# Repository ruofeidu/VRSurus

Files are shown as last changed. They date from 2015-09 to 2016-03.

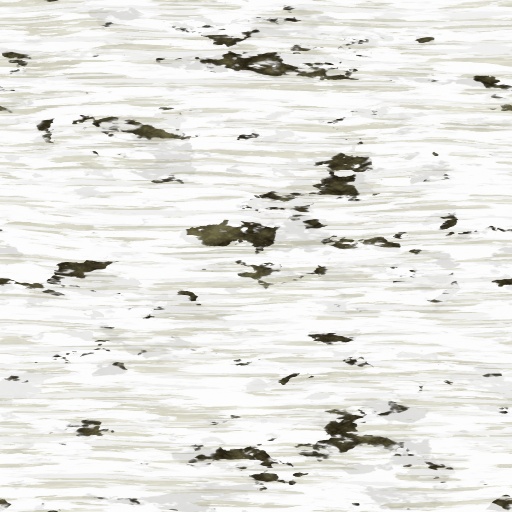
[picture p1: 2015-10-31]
images/bark3-diffuse.jpg

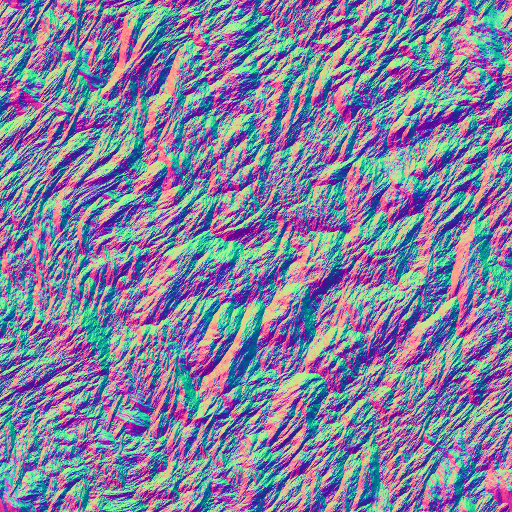
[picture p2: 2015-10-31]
images/bark-normal.jpg

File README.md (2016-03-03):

# VRSurus: A Tangible Virtual-Reality Game for Environmental Protection

### Introduction
We introduce VRSurus, a tangible serious game that aims to inspire children to protect the environment in immersive virtual reality (VR). VRSurus is built upon a physical puppet and a VR head-mounted display (Oculus Rift DK2) to create "tangible virtual animatronics". The player will act as a little elephant called Surus to prevent evil humanbeings from invading the forest. The player is able to use four gestures to cast magical spells: swiping left, swiping right, shaking and jumping. Servos, selonoids and vibration motors will assist with the puppet animation visible to the audience and provide haptic feedback for the player. VRSurus contributes to the HCI, animatronics and tangible computing community by integrating immersive interactive graphics together with gesture recognition and tangible feedback. The game is presented at the UIST 2015 Student Innovation Contest. Video and more details will be publicly available via www.vrsurus.com.

### Story Background
Once upon a time, there was a little elephant named Surus, living happily in a beautiful forest - Green Woodland.
However, in a cloudy day, evil human beings started to invade Green Woodland. They threw garbage everywhere; they used axes to cut down green trees; they even started to construct factories to pollute the air!
The magical elf of Green Woodland assigned you, Surus, to save the forest and rescue the nature! Surus is empowered with the magic of wind, water and fire to destroy the messy garbage, evil lumbermen and destructive factories. 

### Technical Brief
The software is built with WebGL and WebVR, which enables the game to be cross-platform for Oculus Rift and Google Cardboard. We rendered photo-realistic forest environment, GPU-based particle effects as well as skeleton-animated elephants, lumberman and factory. We use HTML5 (WebGL, WebVR, 3D Audio API), Javascript (jQuery & Three.js), GLSL ES (WebGL), PHP (ThinkPHP), MySQL and Java (Processing) to implement the entire system. 

The hardware consists of gyroscope, accelerometer, compass, servos, vibration motors, selonoids, batteries, 3D-printed skeletons and cases. 

### Authors
We the NinjaTerp team! Feel free to visit VRSurus.com for more information!
* Ruofei Du (http://duruofei.com)
   *  [Augmentarium Lab] | [UMIACS] | [University of Maryland, College Park]
   * Team Captain, Graphics (WebGL + WebVR + Model + 3D Audio) and Web Server (PHP + MySQL + Part of Java)
* Liang He (http://lianghe.me)
   * Makeability Lab | [HCIL] | [UMIACS] | [University of Maryland, College Park] 
   * Fabrication (3D Modeling, Printing), Logo, Video and Hardware (Arduino, Java)

### Advisor
* Amitabh Varshney (http://www.cs.umd.edu/~varshney)

### Presentation
The game is presented on UIST 2015 Student Innovation Contest. The project is still work-in-progress for future publications. For now, please cite
> Du, R., He, L. VRSurus: Enhancing Interactivity and Tangibility of Puppets in Virtual Reality. In Proceedings of the 33rd Annual ACM Conference Extended Abstracts on Human Factors in Computing Systems (CHI 16), 8 pages. ACM.

If you find our idea or code useful for your projects.

### How to Use
Feel free to run the entire codebase or build partial code such as only the VR game or only the open-sourced hardware.

##### VRSurus Game
The game is running a webserver with WebGL and WebVR technologies. Here is a step-by-step tutorial:
* Install [XAMPP] to setup a PHP + Apache + MySQL environment.
* Run Apache and MySQL server.
* Clone the git reporsitory and place all code into the XAMPP folder under htdocx/ninjaterp
* Open http://localhost/PHPMyAdmin, Create a new table called vrsurus and import the MySQL data from server/mysql/mysql.sql into the vrsurus table.
* Download the [Oculus Runtime] (v0.6.1 tested, v0.8 should also work) and [Chromium build for WebVR]
* Run http://localhost/ninjaterp using [Chromium build for WebVR]
* Press space on the keyboard to start the tutorial, press enter on the keyboard to start the game.
* You can control Surus using three ways:
    * Keyboard: 1, 2, 3, 4.
    * XBox: A, B, X, Y.
    * Puppet: Swipe left, swipe right, shake, thrust.

If you start the game and observe the scene flying high into the sky, then probably you are not using the correct browser: [Chromium build for WebVR]
### Instructions
##### Gecture
Please close the mouth of the puppet when performing any gesture to attack enemies. Then open the mouth.

##### Wind Spells
Swipe leftward or rightward to clean the garbage.

##### Water Spell
Shake the nose up and down to sweep the lumberman(an) away

##### Fire Spell
Punch forward to destroy the evil factories.

### Code
[Code on Github]

### Technical Challenges
This project is realy ambitious. We iterate numerous times, tried and failed in both software and hardware: anmiated models & 3D printing & miniaturization. 

### Acknowledgement
The authors would like to thank [Sai Yuan] from Department of Animal and Avian Science of [University of Maryland, College Park] for helping with splendid sewing and awesome vocal, background music and audio effects. We also thank 3DRT.com for providing a student discount for the awesome 3D models. And, thanks to [Augmentarium Lab] for funding this project.

### License
Creative Commons  Attribution-NonCommercial 4.0 International 

### Version
1.0.0

[Code on Github]: https://github.com/animatronics/ninjaterp
[Augmentarium Lab]:http://augmentarium.umiacs.umd.edu
[GVIL]:http://www.cs.umd.edu/gvil/
[HCIL]:http://www.cs.umd.edu/hcil/
[UMIACS]:http://umiacs.umd.edu
[University of Maryland, College Park]:http://www.umd.edu
[XAMPP]: https://www.apachefriends.org/index.html
[Oculus Runtime]: https://developer.oculus.com/downloads/pc/0.6.0.1-beta/Oculus_Runtime_for_Windows/
[Chromium build for WebVR]: https://drive.google.com/folderview?id=0BzudLt22BqGRbW9WTHMtOWMzNjQ
[Sai Yuan]: http://veritayuan.com/

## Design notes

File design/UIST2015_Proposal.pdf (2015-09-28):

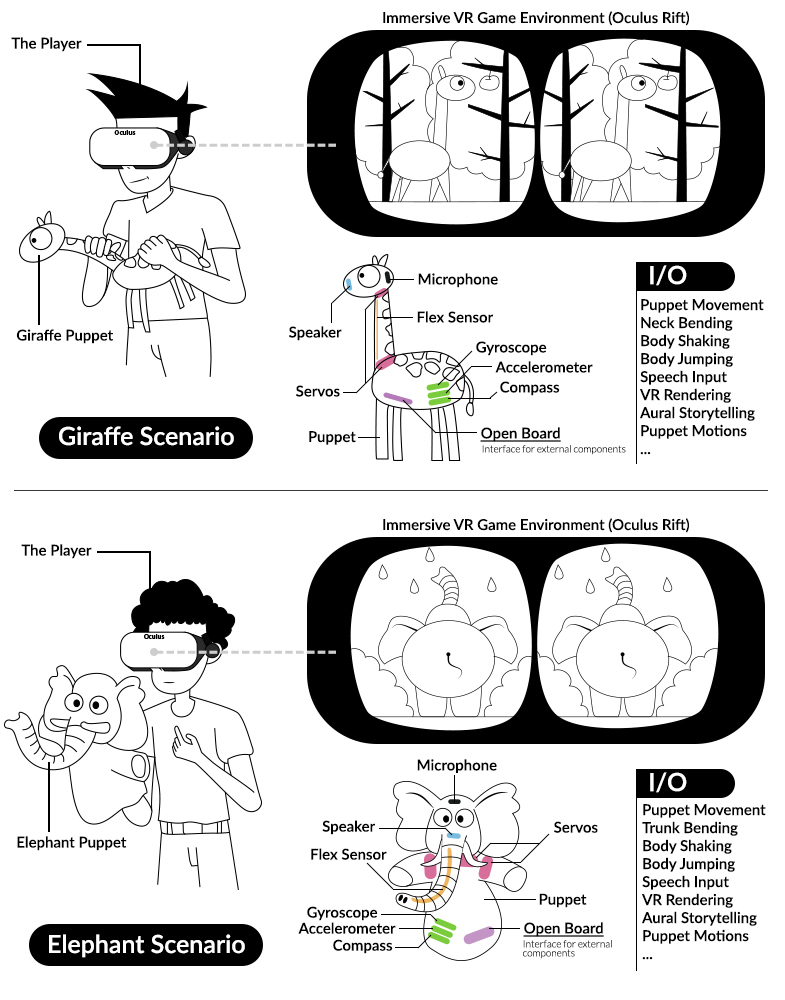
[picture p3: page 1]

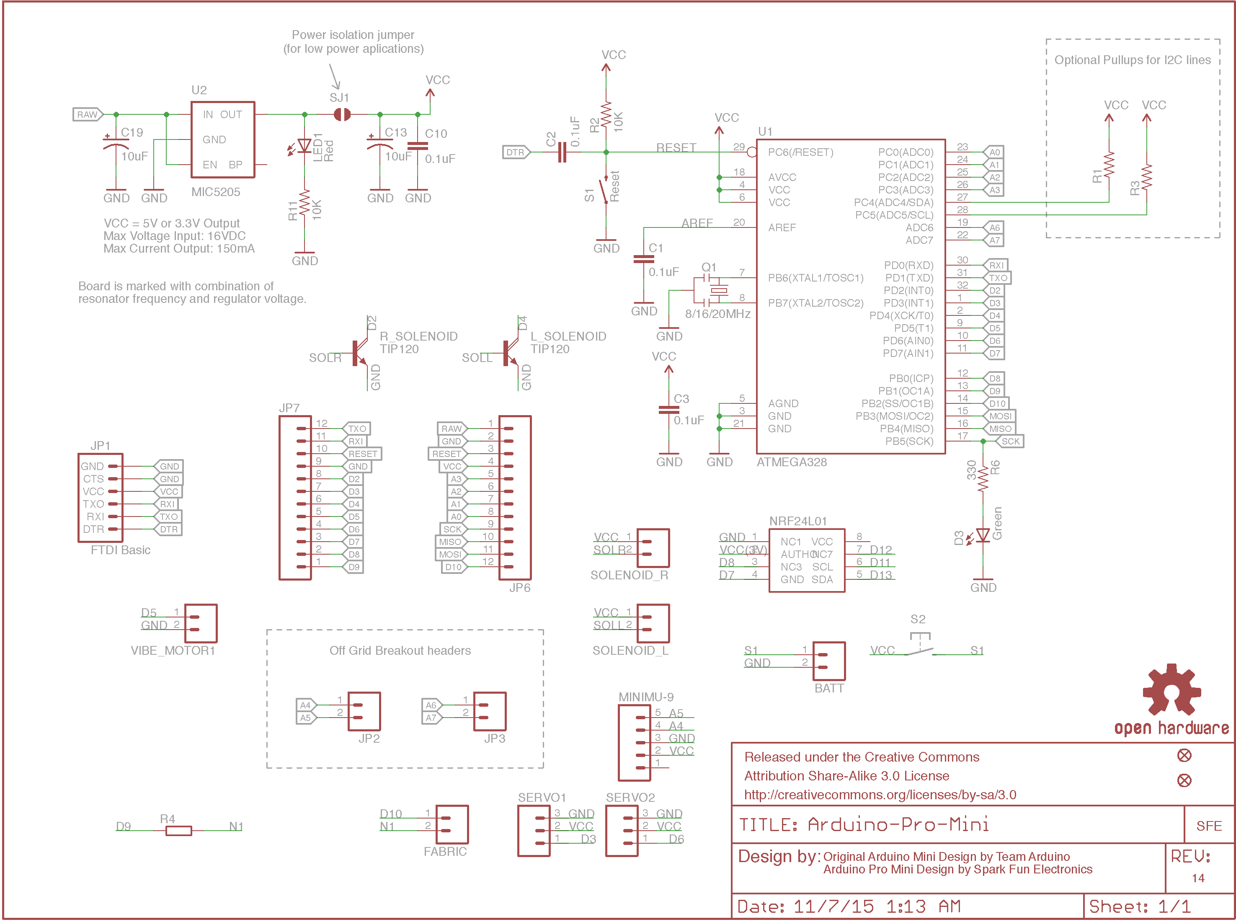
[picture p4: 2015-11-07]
hardware/circuit/Circuit.png

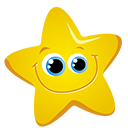
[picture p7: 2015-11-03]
images/star.png

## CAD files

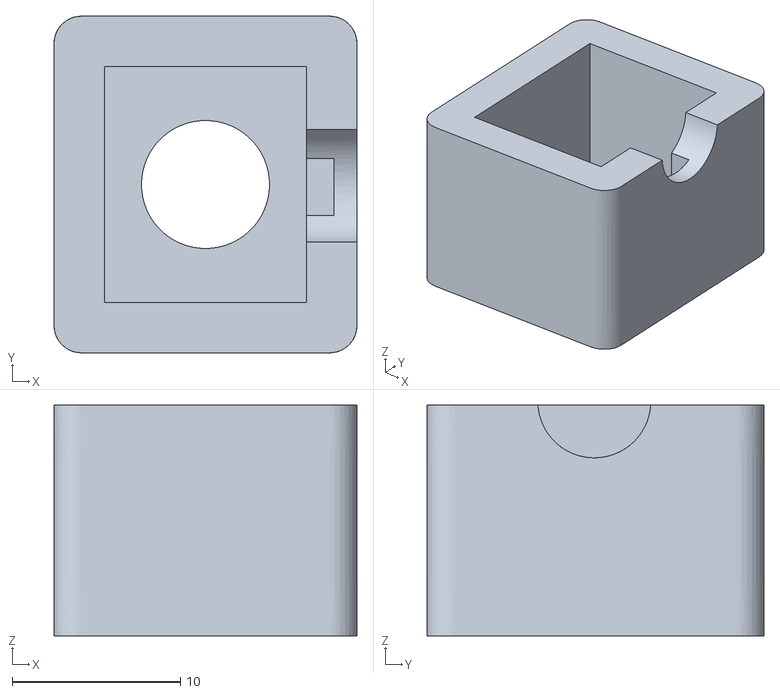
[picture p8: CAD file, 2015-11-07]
hardware/fabrication/solenoid_low1.stl
18.0 x 20.0 x 13.7

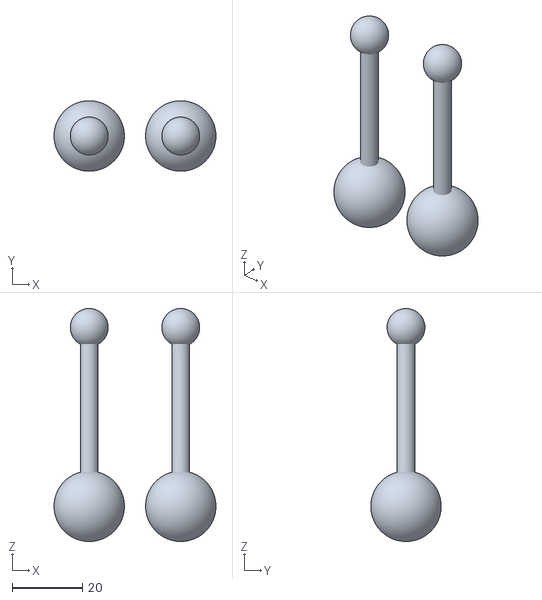
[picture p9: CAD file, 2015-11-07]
hardware/fabrication/arm.stl
46.0 x 20.0 x 66.2

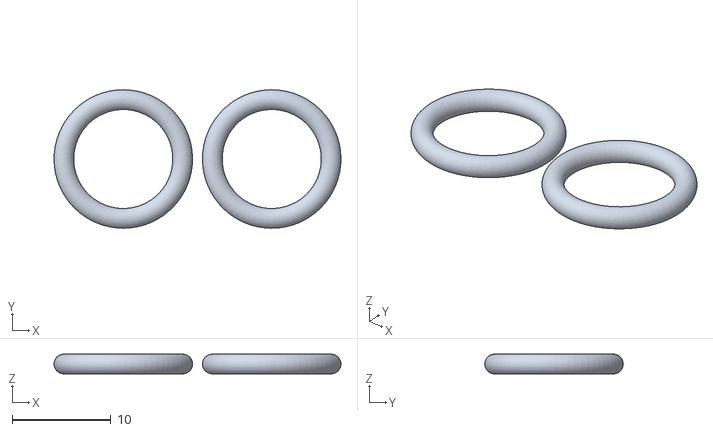
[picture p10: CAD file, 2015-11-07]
hardware/fabrication/arm_clip.stl
29.0 x 14.0 x 2.00

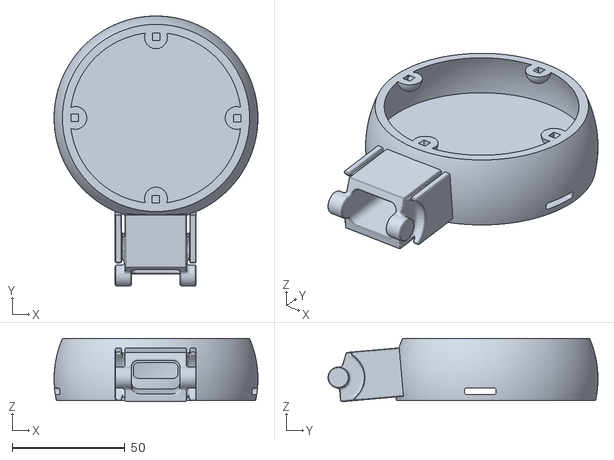
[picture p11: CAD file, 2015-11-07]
hardware/fabrication/cap_low_new.stl
90.6 x 120.0 x 28.1

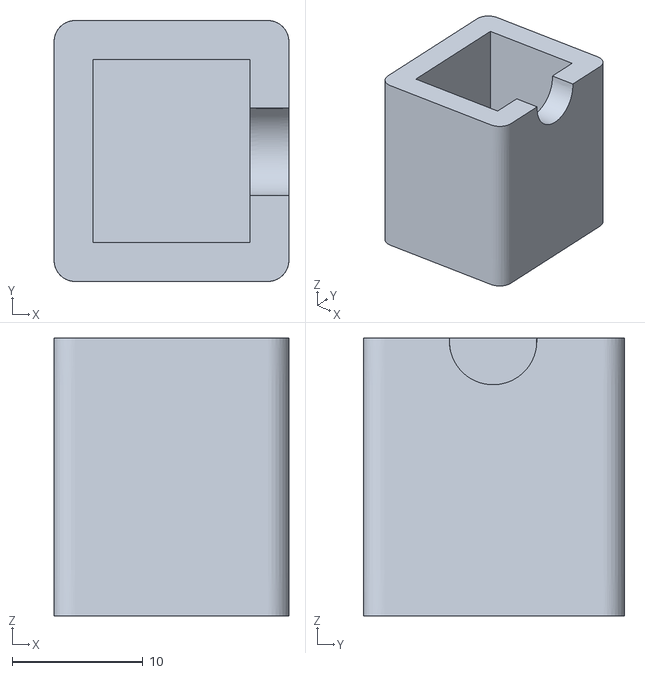
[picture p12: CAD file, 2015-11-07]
hardware/fabrication/solenoid_up1.stl
18.0 x 20.0 x 21.3

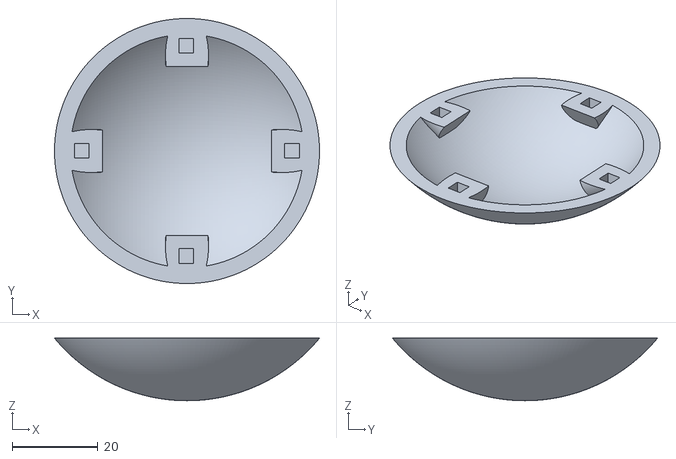
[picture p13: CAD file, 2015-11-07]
hardware/fabrication/cap_up.stl
61.7 x 61.7 x 14.6

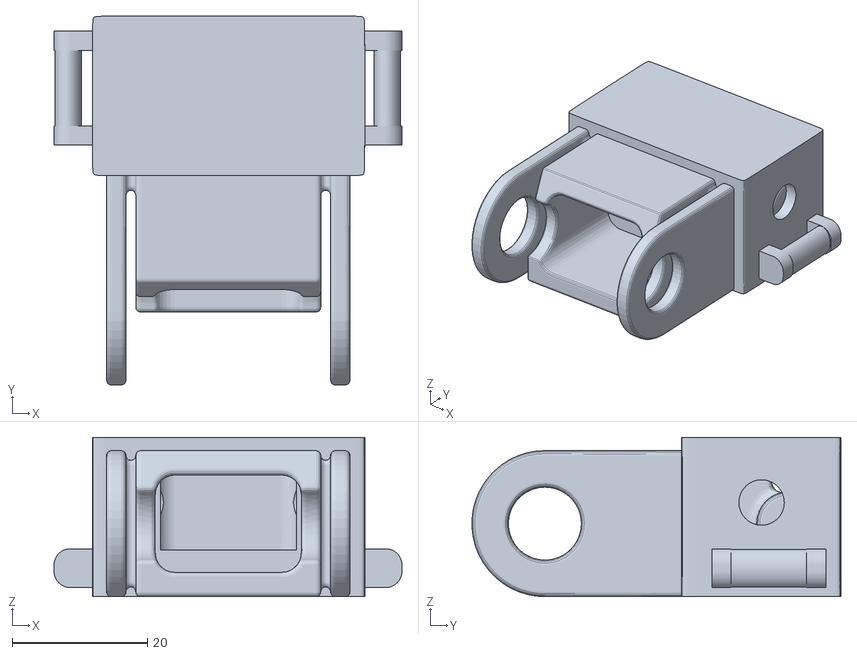
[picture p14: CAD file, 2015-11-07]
hardware/fabrication/end_node.stl
51.4 x 54.6 x 23.6

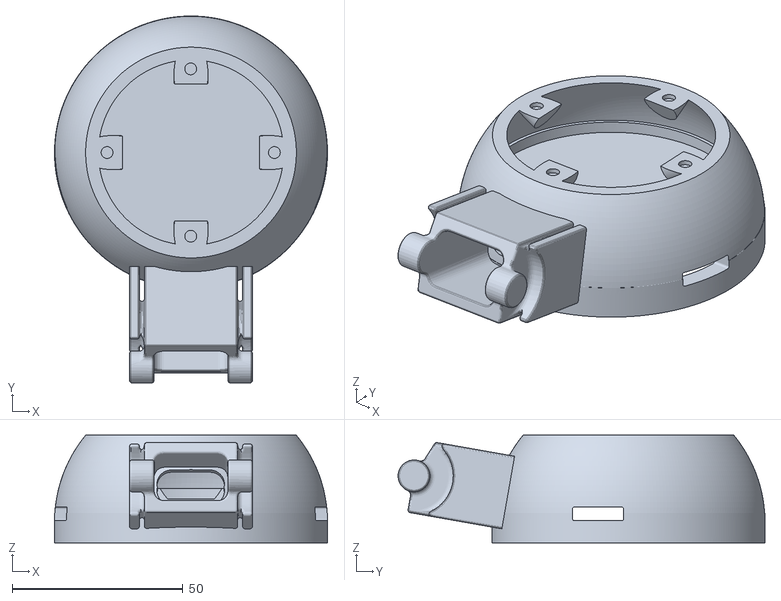
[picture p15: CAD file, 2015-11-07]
hardware/fabrication/cap_low.stl
80.0 x 107.5 x 31.6

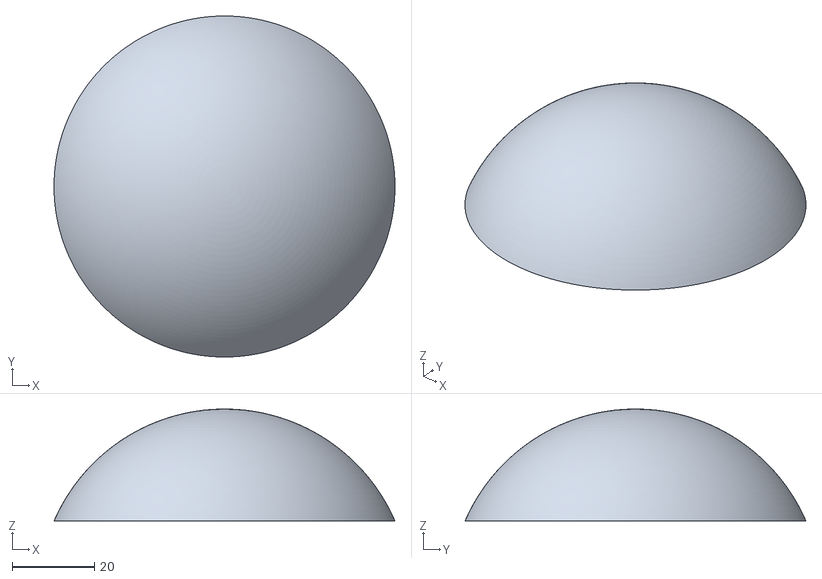
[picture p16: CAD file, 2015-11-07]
hardware/fabrication/cap_up_new.stl
83.1 x 83.1 x 27.3

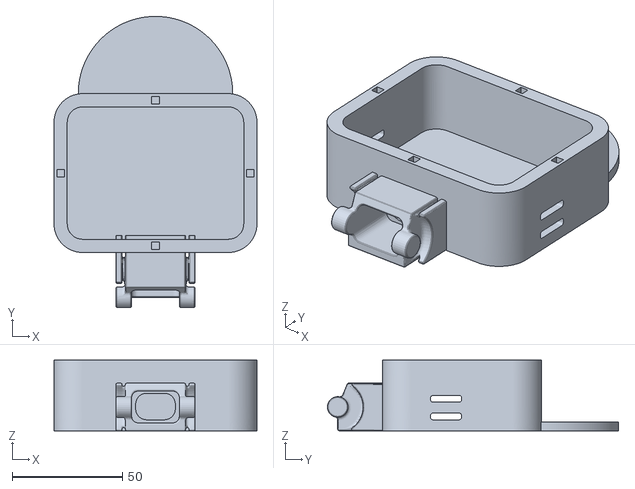
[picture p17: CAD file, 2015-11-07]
hardware/fabrication/cap_low_updated.stl
92.0 x 132.0 x 32.0

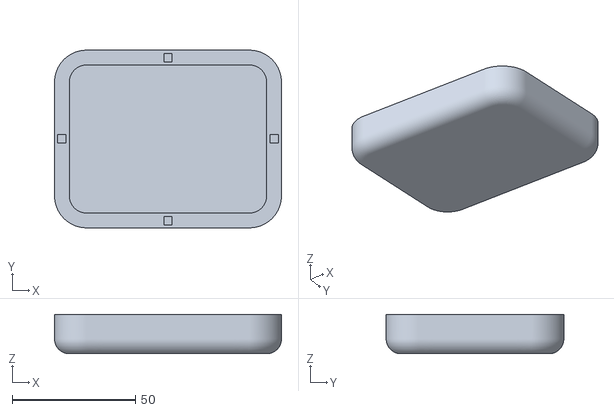
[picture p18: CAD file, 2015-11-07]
hardware/fabrication/cap_up_updated.stl
92.0 x 72.0 x 16.0

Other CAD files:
hardware/fabrication/solenoid_low2.stl
hardware/fabrication/solenoid_up2.stl
hardware/fabrication/accessaries.3dm
hardware/fabrication/end_node+solenoid_case.3dm

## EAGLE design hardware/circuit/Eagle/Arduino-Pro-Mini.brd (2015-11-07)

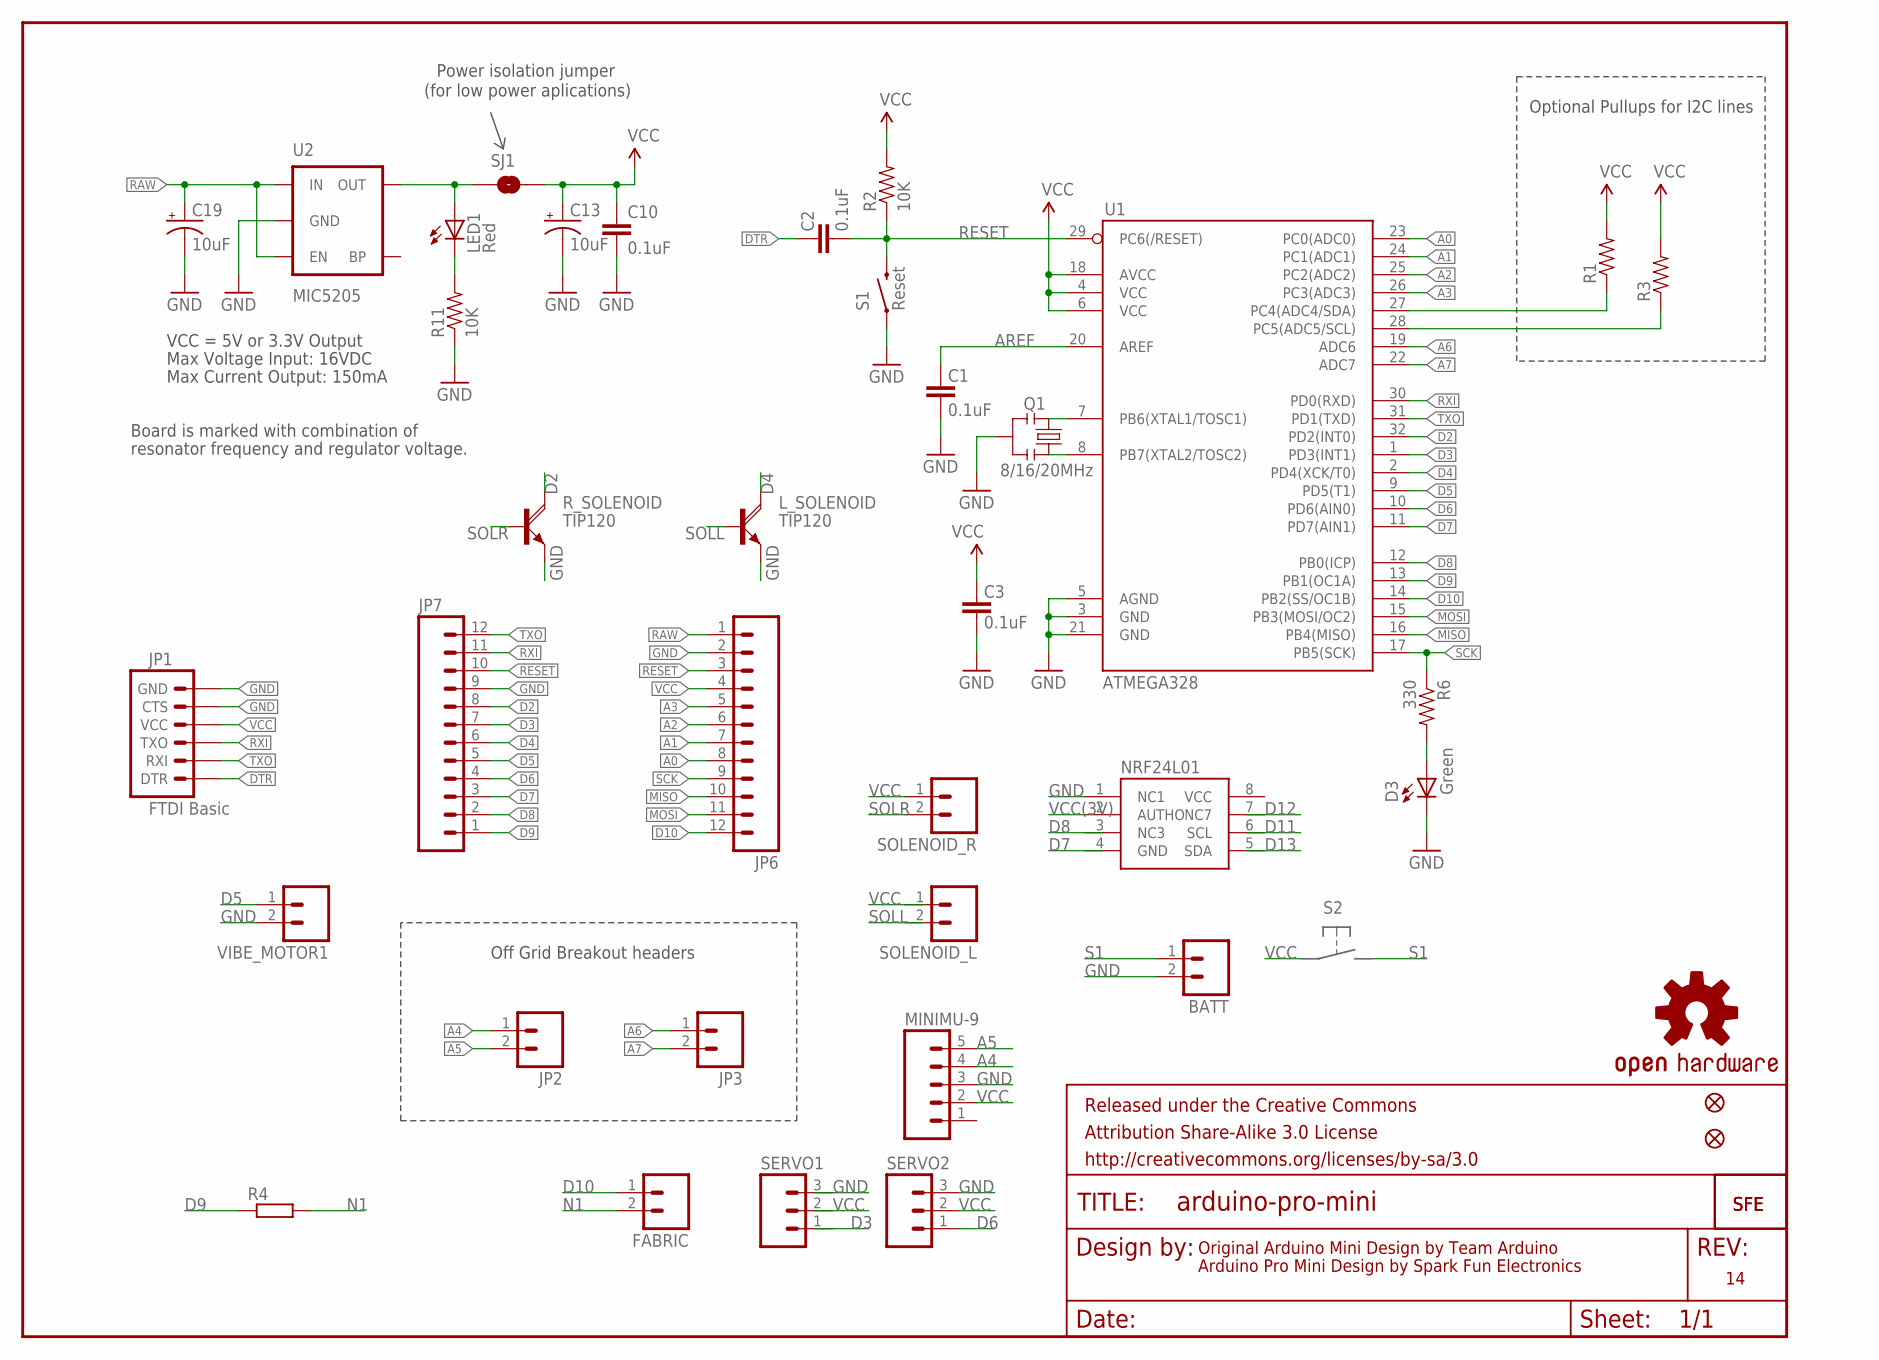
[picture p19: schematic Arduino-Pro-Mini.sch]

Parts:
BATT: M02PTH; 1X02
C1, C2, C3, C10: 0.1uF; 0603-CAP
C13, C19: 10uF; EIA3216
D3: Green; 0603-LED-ALT1
FABRIC: M02PTH; 1X02
FRAME1: FRAME-LETTER; CREATIVE_COMMONS
JP1: FTDI Basic; 1X06
JP2, JP3: M02PTH; 1X02
JP5, JP8: FIDUCIALUFIDUCIAL; MICRO-FIDUCIAL
JP6, JP7: M12PTH; 1X12
LED1: Red; 0603-LED-ALT1
L_SOLENOID: TIP120; TO220AH
MINIMU-9: M05; 05P
NRF24L01: ATAES132; SOIC8
Q1: 8/16/20MHz; RESONATOR-SMD-1:1
R1, R3: RESISTOR0603-RES; 0603-RES
R2, R11: 10K; 0603-RES
R4: R-EU_0204/5; 0204/5
R6: 330; 0603-RES
R_SOLENOID: TIP120; TO220AH
S1: Reset; TACTILE-SWITCH-SMD-ALT01
SERVO1, SERVO2: M03; 03P
SJ1: SOLDERJUMPERNC; SJ_2S
SOLENOID_L: M02PTH; 1X02
SOLENOID_R: M02PTH; 1X02
U1: ATMEGA328; TQFP32-08
U2: MIC5205; SOT23-5
U$1: LOGO-SFESK; SFE-LOGO-FLAME
U$3: OSHW-LOGOS; OSHW-LOGO-S
U$11: LOGO-SFENEW; SFE-NEW-WEBLOGO
VIBE_MOTOR1: M02PTH; 1X02

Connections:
A0: JP6.8, U1.23 (PC0(ADC0))
A1: JP6.7, U1.24 (PC1(ADC1))
A2: JP6.6, U1.25 (PC2(ADC2))
A3: JP6.5, U1.26 (PC3(ADC3))
A4: JP2.1, MINIMU-9.4, R1.1, U1.27 (PC4(ADC4/SDA))
A5: JP2.2, MINIMU-9.5, R3.1, U1.28 (PC5(ADC5/SCL))
A6: JP3.1, U1.19 (ADC6)
A7: JP3.2, U1.22 (ADC7)
AREF: C1.2, U1.20 (AREF)
D2: JP7.8, R_SOLENOID.C, U1.32 (PD2(INT0))
D3: JP7.7, U1.1 (PD3(INT1))
D4: JP7.6, L_SOLENOID.C, U1.2 (PD4(XCK/T0))
D5: JP7.5, U1.9 (PD5(T1)), VIBE_MOTOR1.1
D6: JP7.4, SERVO2.1, U1.10 (PD6(AIN0))
D7: JP7.3, U1.11 (PD7(AIN1))
D8: JP7.2, U1.12 (PB0(ICP))
D9: JP7.1, R4.1, U1.13 (PB1(OC1A))
D10: FABRIC.1, JP6.12, U1.14 (PB2(SS/OC1B))
DTR: C2.2, JP1.1 (DTR)
GND: BATT.2, C1.1, C3.1, C10.2, C13.C (-), C19.C (-), D3.C, JP1.5 (CTS), JP1.6 (GND), JP6.2, JP7.9, L_SOLENOID.E, MINIMU-9.3, NRF24L01.1 (NC1), NRF24L01.4 (GND), Q1.2, R11.1, R_SOLENOID.E, S1.1, S1.2 (1), SERVO2.3, U1.3 (GND), U1.5 (AGND), U1.21 (GND), U2.2 (GND), VIBE_MOTOR1.2
MISO: JP6.10, U1.16 (PB4(MISO))
MOSI: JP6.11, U1.15 (PB3(MOSI/OC2))
N1: FABRIC.2, R4.2
unnamed: Q1.3, U1.8 (PB7(XTAL2/TOSC2))
unnamed: Q1.1, U1.7 (PB6(XTAL1/TOSC1))
unnamed: LED1.A, SJ1.1, U2.5 (OUT)
unnamed: LED1.C, R11.2
unnamed: D3.A, R6.2
RAW: C19.A (+), JP6.1, U2.1 (IN), U2.3 (EN)
RESET: C2.1, JP6.3, JP7.10, R2.1, S1.3 (2), S1.4 (2), U1.29 (PC6(/RESET))
RXI: JP1.3 (TXO), JP7.11, U1.30 (PD0(RXD))
S1: BATT.1
SCK: JP6.9, R6.1, U1.17 (PB5(SCK))
SOLL: L_SOLENOID.B
SOLR: R_SOLENOID.B, SOLENOID_R.2
TXO: JP1.2 (RXI), JP7.12, U1.31 (PD1(TXD))
VCC: C3.2, C10.1, C13.A (+), JP1.4 (VCC), JP6.4, MINIMU-9.2, NRF24L01.8 (VCC), R1.2, R2.2, R3.2, SERVO2.2, SJ1.2, SOLENOID_R.1, U1.4 (VCC), U1.6 (VCC), U1.18 (AVCC)
VCC(3V): NRF24L01.2 (AUTHO)

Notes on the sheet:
Original Arduino Mini Design by Team Arduino
Arduino Pro Mini Design by Spark Fun Electronics
Max Voltage Input: 16VDC
Max Current Output: 150mA
Board is marked with combination of
resonator frequency and regulator voltage.
VCC = 5V or 3.3V Output
Optional Pullups for I2C lines
Off Grid Breakout headers
Power isolation jumper
(for low power aplications)

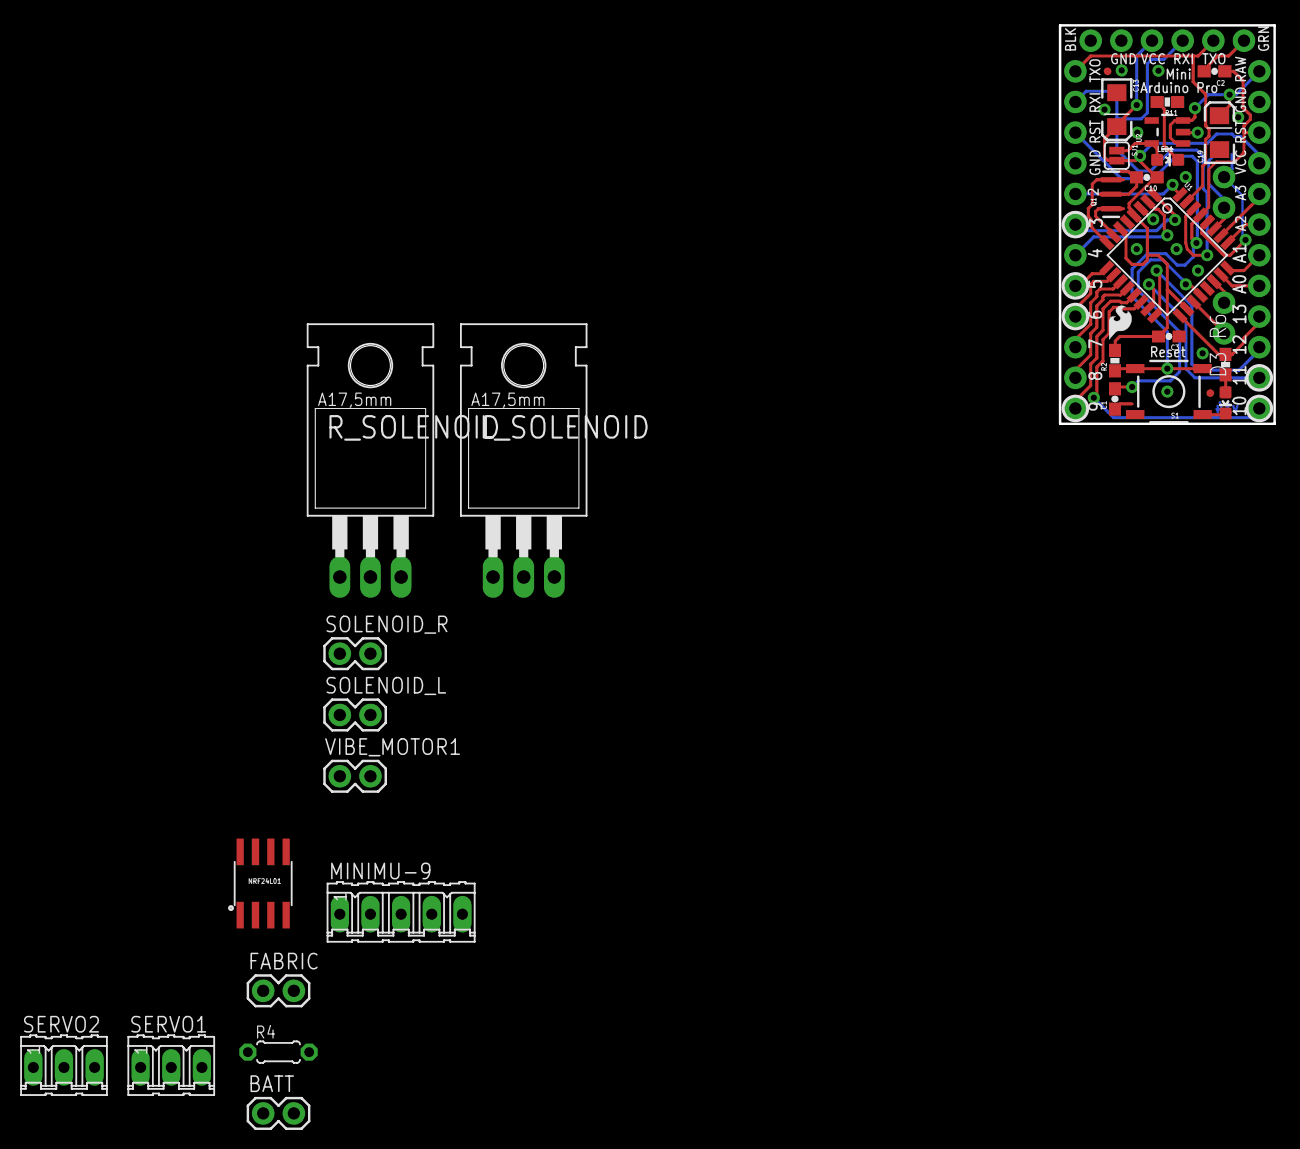
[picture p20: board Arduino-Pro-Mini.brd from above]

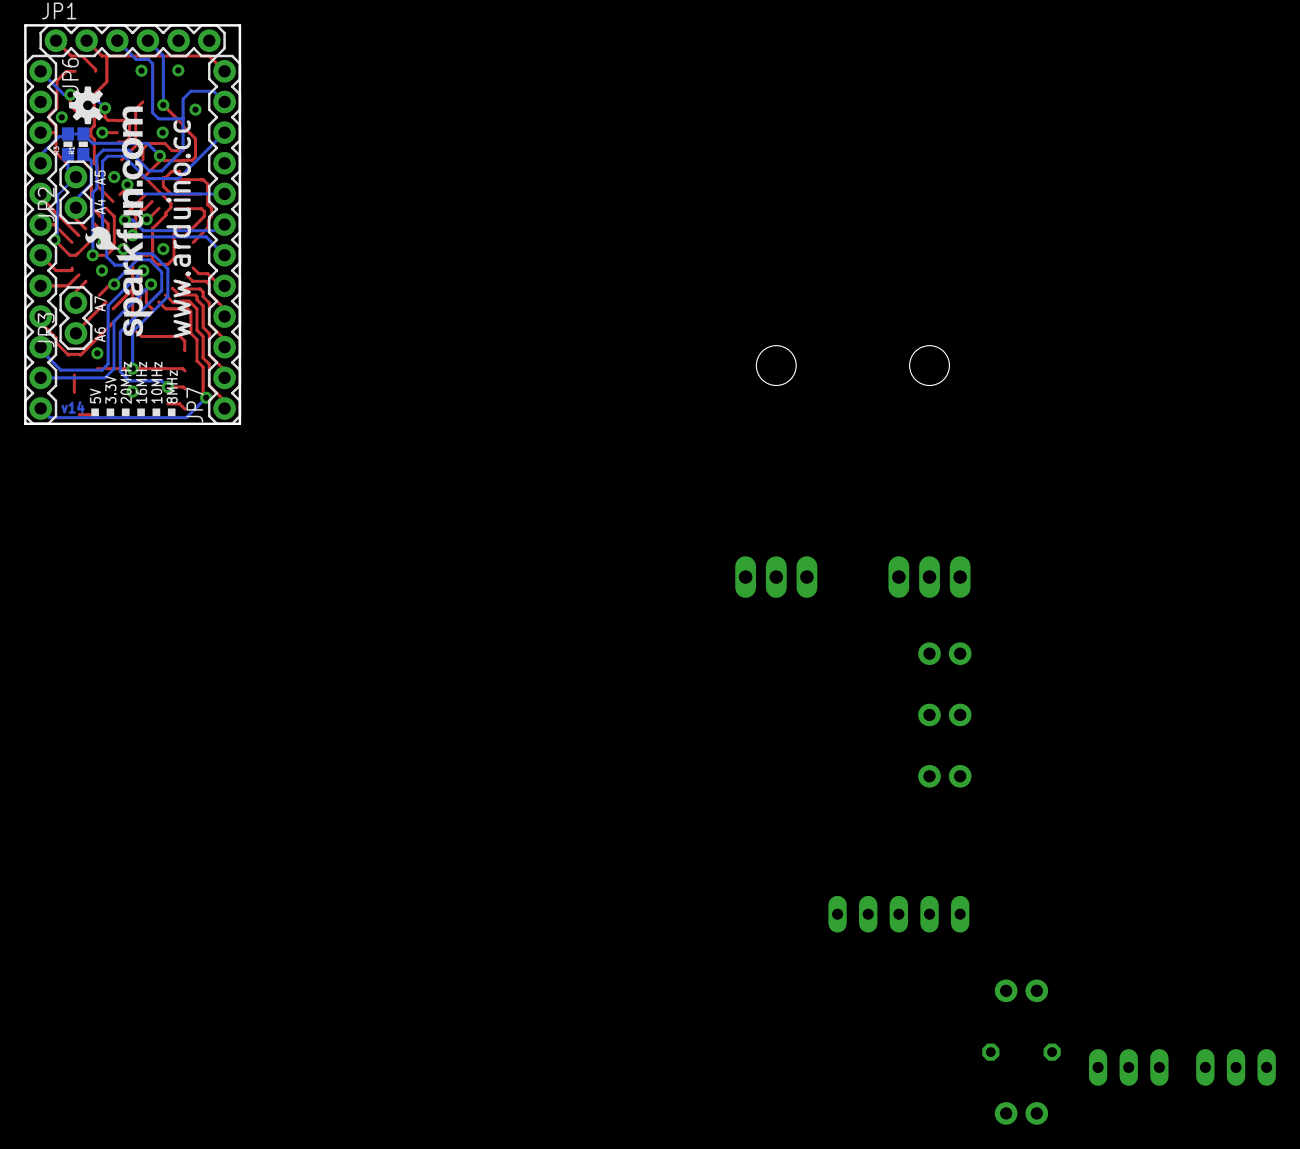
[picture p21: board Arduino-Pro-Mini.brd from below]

Board: 2 copper layers, 17.8 x 33.0 mm, 41 parts (9 on the bottom side), 35 nets.

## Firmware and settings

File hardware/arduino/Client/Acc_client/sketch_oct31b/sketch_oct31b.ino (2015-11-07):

#include <SPI.h>
#include <Mirf.h>
#include <MirfHardwareSpiDriver.h>
#include <MirfSpiDriver.h>
#include <nRF24L01.h>

#include <QueueList.h>

#include <Wire.h>
#include <LSM303.h>


LSM303 compass;

#define GRAVITY 256         // this equivalent to 1G in the raw data coming from the accelerometer 

// X axis pointing forward
// Y axis pointing to the right 
// and Z axis pointing down.
int SENSOR_SIGN[3] = {-1, -1, -1};  // correct directions x, y, z - accelerometer
int AN[3]; //array that stores accelerometer data
int AN_OFFSET[3] = {0,0,0}; //Array that stores the Offset of the sensors

int accel_x;
int accel_y;
int accel_z;

long timer=0;   //general purpuse timer
long timer_old;

void Accel_Init()
{
  compass.init();
  compass.enableDefault();
  switch (compass.getDeviceType())
  {
    case LSM303::device_D:
      compass.writeReg(LSM303::CTRL2, 0x18); // 8 g full scale: AFS = 011
      break;
    case LSM303::device_DLHC:
      compass.writeReg(LSM303::CTRL_REG4_A, 0x28); // 8 g full scale: FS = 10; high resolution output mode
      break;
    default: // DLM, DLH
      compass.writeReg(LSM303::CTRL_REG4_A, 0x30); // 8 g full scale: FS = 11
  }
}

// Reads x,y and z accelerometer registers
void Read_Accel()
{
  compass.readAcc();
  
  AN[0] = compass.a.x >> 4; // shift left 4 bits to use 12-bit representation (1 g = 256)
  AN[1] = compass.a.y >> 4;
  AN[2] = compass.a.z >> 4;
  accel_x = SENSOR_SIGN[0] * (AN[0] - AN_OFFSET[0]);
  accel_y = SENSOR_SIGN[1] * (AN[1] - AN_OFFSET[1]);
  accel_z = SENSOR_SIGN[2] * (AN[2] - AN_OFFSET[2]);
}

void I2C_Init()
{
  Wire.begin();
}

void setup() {
  Serial.begin(9600);
  
  I2C_Init();
  delay(1500);
  
  Accel_Init();
  delay(20);

  for (int i = 0; i < 32; i++)    // We take some readings...
  {
    Read_Accel();
    for (int y = 0; y < 3; y++)   // Cumulate values
      AN_OFFSET[y] += AN[y];
    delay(20);
  }

  for (int y = 0; y < 3; y++)
    AN_OFFSET[y] = AN_OFFSET[y]/32;

  AN_OFFSET[2] -= GRAVITY*SENSOR_SIGN[2];

  //Serial.println("Offset:");
  //for(int y=0; y<3; y++)
  //  Serial.println(AN_OFFSET[y]);

  delay(2000);
  timer = millis();
  delay(20);

  // Initialize the client
  Mirf.spi = &MirfHardwareSpi;
  Mirf.init();
  
  // Configure reciving address.
  Mirf.setRADDR((byte *)"clie1");
  Mirf.payload = 9;
  Mirf.config();
  Serial.println("Beginning ... "); 
}

void loop() {
  if ((millis()-timer) >= 1){  // Main loop runs at 1000Hz
    timer_old = timer;
    timer = millis();

    Read_Accel();

    byte data[Mirf.payload];
    byte temp;
    
    if (accel_x <= 0) {
      accel_x = -accel_x;
      data[0] = '-';
    } else {
      data[0] = '+';
    }
    data[1] = (byte)((accel_x & 0xFF00) >> 8);
    data[2] = (byte)(accel_x & 0xFF);

    if (accel_y <= 0) {
      accel_y = -accel_y;
      data[3] = '-';
    } else {
      data[3] = '+';
    }
    data[4] = (byte)((accel_y & 0xFF00) >> 8);
    data[5] = (byte)(accel_y & 0xFF);

    if (accel_z <= 0) {
      accel_z = -accel_z;
      data[6] = '-';
    } else {
      data[6] = '+';
    }
    data[7] = (byte)((accel_z & 0xFF00) >> 8);
    data[8] = (byte)(accel_z & 0xFF);

    // sending data
    Mirf.setTADDR((byte *)"serv1");
    Mirf.send(data);
    while(Mirf.isSending()){}
    Serial.println("Finished sending");
    
    Serial.println("Acc: ");
    Serial.print(data[0]);
    Serial.print(", ");
    Serial.print(data[1]);
    Serial.print(", ");
    Serial.println(data[2]);
  
    Serial.print(data[3]);
    Serial.print(", ");
    Serial.print(data[4]);
    Serial.print(", ");
    Serial.println(data[5]);
  
    Serial.print(data[6]);
    Serial.print(", ");
    Serial.print(data[7]);
    Serial.print(", ");
    Serial.println(data[8]);
    Serial.println("");
  }
}

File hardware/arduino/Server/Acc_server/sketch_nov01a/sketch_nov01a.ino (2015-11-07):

#include <SPI.h>
#include <Mirf.h>
#include <nRF24L01.h>
#include <MirfHardwareSpiDriver.h>

int accel_x, accel_y, accel_z;

void setup(){
  Serial.begin(9600);
  Mirf.spi = &MirfHardwareSpi;
  Mirf.init();

  Mirf.setRADDR((byte *)"serv1");

  Mirf.payload = 9;
  
  Mirf.config();

}

void loop(){

  byte data[Mirf.payload];
  

  if(!Mirf.isSending() && Mirf.dataReady()){
    
    Mirf.getData(data);
   
    // Mirf.setTADDR((byte *)"clie1");
    // Mirf.send(data);
    
    accel_x = data[1];
    accel_x = accel_x << 8 | data[2];
    if(data[0] == '-'){
      accel_x = -accel_x;
    }

    accel_y = data[4];
    accel_y = accel_y << 8 | data[5];
    if(data[3] == '-'){
      accel_y = -accel_y;
    }

    accel_z = data[7];
    accel_z = accel_z << 8 | data[8];
    if(data[6] == '-'){
      accel_z = -accel_z;
    }
    printData();
    
  }
  //printdata();
}

void printdata(void){
  Serial.print("Acc: ");
  Serial.print(accel_x);
  Serial.print(", ");
  Serial.print(accel_y);
  Serial.print(", ");
  Serial.println(accel_z);
}
void printData(void){
  Serial.print(accel_x);
  Serial.print(',');
  Serial.print(accel_y);
  Serial.print(',');
  Serial.print(accel_z);
  Serial.print('#');
}

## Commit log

2015-09-28 Added design and hardware
    [head-extender-20mm.stl, head-extender-40mm.stl, head-frame-short-mouth.stl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]
2015-10-15 First version: animated Springer, one weekends' work.
2015-10-25 added sound, adjusted camera position for VR.
2015-11-02 add gaming process, die and vanish, yeah!
2015-11-04 web server and test case done.
2015-11-07 update readme signals.
    [head-extender-20mm.stl, head-extender-40mm.stl, head-frame-short-mouth.stl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]
2015-11-07 open-sourced hardware, 3D printed models added. Final version before the trip!
    [Arduino-Pro-Mini.brd, Arduino-Pro-Mini.sch, accessaries.3dm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]

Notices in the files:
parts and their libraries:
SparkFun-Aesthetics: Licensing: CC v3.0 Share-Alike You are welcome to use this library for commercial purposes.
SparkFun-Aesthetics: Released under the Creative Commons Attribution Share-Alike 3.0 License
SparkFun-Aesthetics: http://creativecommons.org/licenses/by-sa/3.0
